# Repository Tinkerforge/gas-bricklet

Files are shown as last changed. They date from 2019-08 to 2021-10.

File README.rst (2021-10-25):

Gas Bricklet
============

**The development of this Bricklet was stopped.**

This repository contains the firmware source code and the hardware design
files. The documentation generator configs can be found at
https://github.com/Tinkerforge/generators

Repository Content
------------------

software/:
 * examples/: Examples for all supported languages
 * build/: Makefile and compiled files
 * src/: Source code of firmware
 * generate_makefile: Shell script to generate Makefile from cmake script

hardware/:
 * Contains kicad project files and additionally schematics as pdf

datasheets/:
 * Contains datasheets for sensors and complex ICs that are used

Hardware
--------

The hardware is designed with the open source EDA Suite KiCad
(http://www.kicad.org). Before you are able to open the files,
you have to install the Tinkerforge kicad-libraries
(https://github.com/Tinkerforge/kicad-libraries). You can either clone
them directly in hardware/ or clone them in a separate folder and
symlink them into hardware/
(ln -s kicad_path/kicad-libraries project_path/hardware). After that you
can open the .pro file in hardware/ with kicad and from there view and
modify the schematics and the PCB layout.

Software
--------

If you want to do your own Brick/Bricklet firmware development we highly
recommend that you use our build environment setup script and read the
tutorial (https://www.tinkerforge.com/en/doc/Tutorials/Tutorial_Build_Environment/Tutorial.html).

To compile the C code we recommend you to install the newest GNU Arm Embedded
Toolchain (https://launchpad.net/gcc-arm-embedded/+download).
You also need to install bricklib2 (https://github.com/Tinkerforge/bricklib2).

You can either clone it directly in software/src/ or clone it in a
separate folder and symlink it into software/src/
(ln -s bricklib_path/bricklib2 project_path/software/src/). Finally make sure to
have CMake installed (http://www.cmake.org/cmake/resources/software.html).

After that you can generate a Makefile from the cmake script with the
generate_makefile shell script (in software/) and build the firmware
by invoking make in software/build/. The firmware (.zbin) can then be found
in software/build/ and uploaded with brickv (click button "Flashing"
on start screen).

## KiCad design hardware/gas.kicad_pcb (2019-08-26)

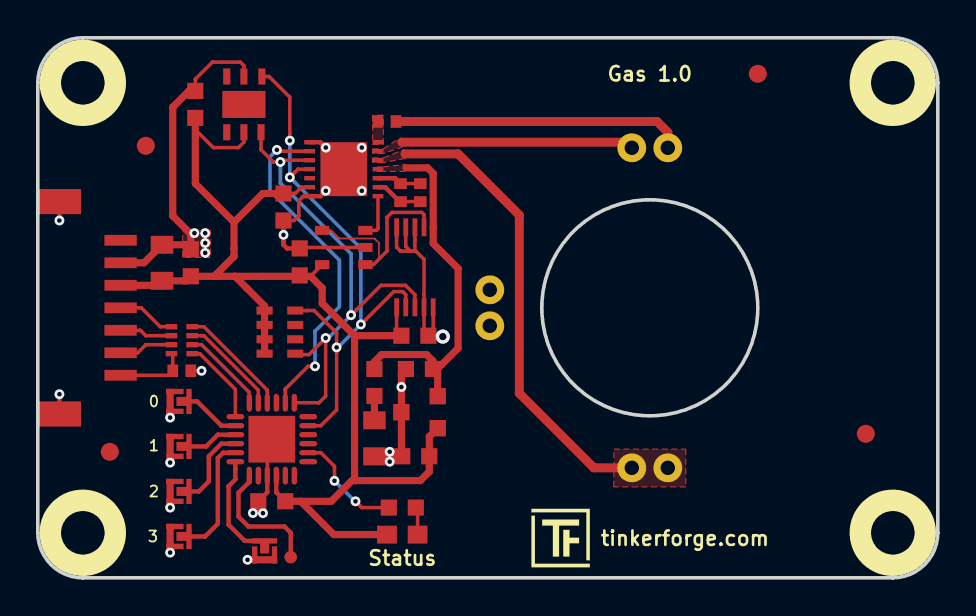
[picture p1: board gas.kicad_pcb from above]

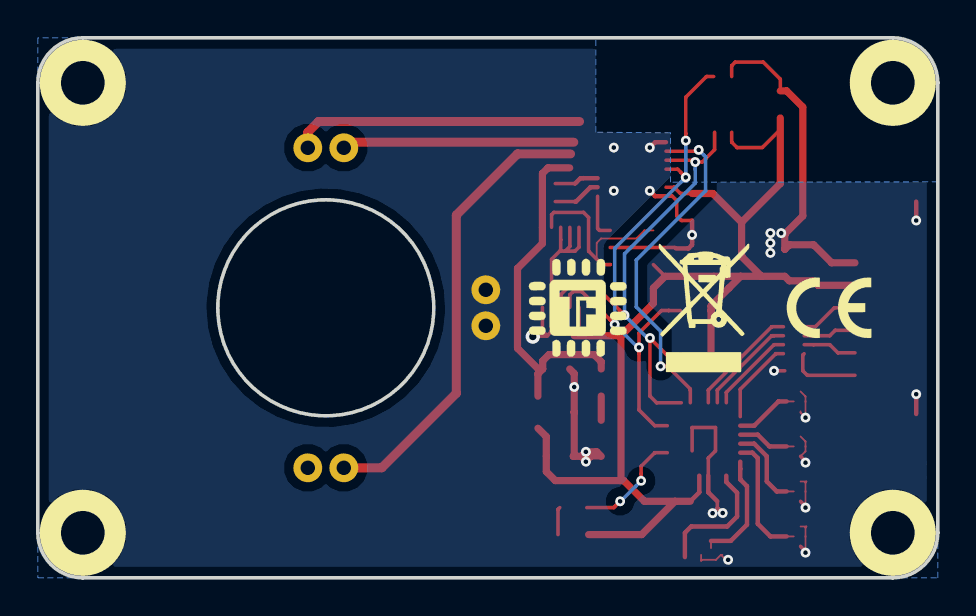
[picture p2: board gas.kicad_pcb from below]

Board: 2 copper layers, 50.0 x 30.0 mm, 43 parts (2 on the bottom side), 31 nets.

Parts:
C1: 220pF; C0402F
C2: 10uF; C0805
C3: 1uF; C0603F
C4, C5, C6, C7, C10, C11, C12: 100nF; C0603F
C8: 10uF TPSA106K010R0900; C0805P
C9: DNP; R0402F
D1: blue; D0603E
Fiducial_Mark: VAL**; Fiducial_Mark
Fiducial_Mark#2, Fiducial_Mark#3, Fiducial_Mark#4: VAL**; Fiducial_Mark
P1: CON-SENSOR2
P2: DEBUG; DEBUG_PAD
P3: BOOT; SolderJumper
P7: 0; SolderJumper
P8: 1; SolderJumper
P9: 2; SolderJumper
P10: 3; SolderJumper
R1, R2: 1k; R0603F
R3: 499k; R0402F
R4: 49,9; R0402F
RP1: 82; 4X0402
RP2: 10k; 0603X4
U1: XMC1300; QFN24-4x4mm-0.5mm
U2, U3, U4, U5: DRILL; DRILL_NP
U6: HDC1080; DFN6-30x30_humidity
U7: ISL60002; SOT23-3
U8: LMP91000; WSON-14-LMP91000
U9: MCP6041; SOT23-5
U10: MCP3423; MSOP10-0.5
U11: spec-sensor
VAL: WEEE_7mm
VAL#2: CE_5mm

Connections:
Enable: U1.20, U8.2
GND: C1.2, C2.1, C3.1, C4.2, C5.2, C6.2, C7.2, C8.2, C10.2, C11.2, C12.2, P1.2, P1.EP, P3.1, P7.1, P8.1, P9.1, P10.1, U1.9, U1.EXP, U6.2, U7.3, U8.1, U8.7, U8.15, U9.2, U10.3, U10.4, U10.5, U10.9, U10.10, U11.2, U11.3
unnamed: C1.1, P1.7, RP1.4
unnamed: C6.1, R2.2, U7.2, U8.11, U10.1
unnamed: C8.1, R2.1
unnamed: C9.1, R3.1, U8.10
unnamed: C9.2, R3.2, U8.9
unnamed: D1.2, R1.2
unnamed: P1.4, RP1.1
unnamed: P1.5, RP1.2
unnamed: P1.6, RP1.3
unnamed: P2.1, U1.7
unnamed: P3.2, U1.6
unnamed: R1.1, U1.14
unnamed: R4.1, U11.5
unnamed: R4.2, U8.14
unnamed: U8.8, U9.3
unnamed: U9.1, U9.4, U10.2
unnamed: U8.12, U11.1, U11.6
unnamed: U8.13, U11.4
S-CLK: RP1.7, U1.23
S-CS: RP1.8, U1.22
S-MISO: RP1.5, U1.1
S-MOSI: RP1.6, U1.24
SCL0: RP2.5, U1.19, U6.6, U8.3, U10.8
SDA0: RP2.8, U1.17, U6.1, U8.4, U10.7
SolderJumper0: P7.2, U1.2
SolderJumper1: P8.2, U1.3
SolderJumper2: P9.2, U1.4
SolderJumper3: P10.2, U1.5
VCC: C2.2, C3.2, C4.1, C5.1, C7.1, C10.1, C11.1, C12.1, D1.1, P1.3, RP2.1, RP2.2, RP2.3, RP2.4, U1.10, U6.5, U7.1, U8.6, U9.5, U10.6

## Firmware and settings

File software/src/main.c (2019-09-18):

/* gas-bricklet
 * Copyright (C) 2019 Olaf Lüke <olaf@tinkerforge.com>
 *
 * main.c: Initialization for Gas Bricklet
 *
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
 * You should have received a copy of the GNU Lesser General Public
 * License along with this library; if not, write to the
 * Free Software Foundation, Inc., 59 Temple Place - Suite 330,
 * Boston, MA 02111-1307, USA.
 */

#include <stdio.h>
#include <stdbool.h>

#include "configs/config.h"

#include "bricklib2/bootloader/bootloader.h"
#include "bricklib2/hal/system_timer/system_timer.h"
#include "bricklib2/logging/logging.h"
#include "communication.h"
#include "gas.h"

int main(void) {
	logging_init();
	logd("Start Gas Bricklet\n\r");

	communication_init();
	gas_init();

	while(true) {
		bootloader_tick();
		communication_tick();
		gas_tick();
	}
}

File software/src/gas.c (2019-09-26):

/* gas-bricklet
 * Copyright (C) 2019 Olaf Lüke <olaf@tinkerforge.com>
 *
 * gas.c: Driver for general Gas type and Concentration detection
 *
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
 * You should have received a copy of the GNU Lesser General Public
 * License along with this library; if not, write to the
 * Free Software Foundation, Inc., 59 Temple Place - Suite 330,
 * Boston, MA 02111-1307, USA.
 */

#include "gas.h"

#include "configs/config_gas.h"
#include "configs/config_lmp91000.h"
#include "configs/config_mcp3423.h"
#include "configs/config_hdc1080.h"

#include "bricklib2/hal/system_timer/system_timer.h"
#include "bricklib2/logging/logging.h"
#include "bricklib2/os/coop_task.h"

#include "communication.h"

#include "lmp91000.h"
#include "hdc1080.h"
#include "mcp3423.h"

#define GAS_CALIBRATION_PAGE           1
#define GAS_CALIBRATION_MAGIC_POS      0
#define GAS_CALIBRATION_DATA_POS       1 // 1 to 14
#define GAS_CALIBRATION_CHECKSUM_POS   15
#define GAS_CALIBRATION_MAGIC          0x12345678

#define GAS_TIME_BETWEEN_INIT_AND_TICK 300 // in ms

#define GAS_ADC_18BIT_MAX              262143
#define GAS_TEMPERATURE_THRESHOLD_ZERO 25.0
#define GAS_TEMPERATURE_THRESHOLD_SPAN 25.0

const uint32_t gas_tiagain_to_rgain[8] = {
	499000, 2735, 3476, 6903, 13618, 32706, 96737, 205713
};

// {Zero Low, Zero High, Span Low, Span High}
const double gas_sensor_compensation[][4] = {
	{0.0,   2.375, 0.6, 0.4}, // CO
	{1.7,  22.5,   1.2, 0.0}, // EtOH
	{0.0,   0.0,   0.3, 0.0}, // H2S
	{0.0,  15.0,   1.2, 0.5}, // SO2
	{0.0, - 1.6,   0.0, 0.4}, // NO2
	{0.0,   0.0,   0.0, 0.5}, // O3
	{0.0,   0.0,   0.0, 0.0}, // IAQ
	{0.0,   0.0,   0.0, 0.0}, // RESP
	{0.0,   0.0,   0.0, 0.0}, // O3/NO
};


CoopTask gas_task;
Gas gas;

uint32_t gas_task_read_register(const uint8_t address, const I2C_FIFO_REG_TYPE reg, const uint32_t length, uint8_t *data) {
	while(gas.i2c_mutex) {
		coop_task_yield();
	}

	gas.i2c_mutex = true;
	gas.i2c_fifo.address = address;

	uint32_t ret = i2c_fifo_coop_read_register(&gas.i2c_fifo, reg, length, data);

	gas.i2c_mutex = false;

	return ret;
}

uint32_t gas_task_write_register(const uint8_t address, const I2C_FIFO_REG_TYPE reg, const uint32_t length, const uint8_t *data, const bool send_stop) {
	while(gas.i2c_mutex) {
		coop_task_yield();
	}

	gas.i2c_mutex = true;
	gas.i2c_fifo.address = address;

	uint32_t ret = i2c_fifo_coop_write_register(&gas.i2c_fifo, reg, length, data, send_stop);

	gas.i2c_mutex = false;

	return ret;
}

uint32_t gas_task_read_direct(const uint8_t address, const uint32_t length, uint8_t *data, const bool restart) {
	while(gas.i2c_mutex) {
		coop_task_yield();
	}

	gas.i2c_mutex = true;
	gas.i2c_fifo.address = address;

	uint32_t ret = i2c_fifo_coop_read_direct(&gas.i2c_fifo, length, data, restart);

	gas.i2c_mutex = false;

	return ret;
}

uint32_t gas_task_write_direct(const uint8_t address, const uint32_t length, const uint8_t *data, const bool send_stop) {
	while(gas.i2c_mutex) {
		coop_task_yield();
	}

	gas.i2c_mutex = true;
	gas.i2c_fifo.address = address;

	uint32_t ret = i2c_fifo_coop_write_direct(&gas.i2c_fifo, length, data, send_stop);

	gas.i2c_mutex = false;

	return ret;
}

void gas_calibration_read(void) {
	uint32_t page[EEPROM_PAGE_SIZE/sizeof(uint32_t)];

	bootloader_read_eeprom_page(GAS_CALIBRATION_PAGE, page);
	uint32_t checksum = 0;
	for(uint8_t i = 0; i < GAS_CALIBRATION_CHECKSUM_POS; i++) {
		checksum = checksum ^ page[i];
	}

	if(page[GAS_CALIBRATION_MAGIC_POS] != GAS_CALIBRATION_MAGIC) {
		logd("Calibration Read: Wrong magic %x != %x\n\r", page[GAS_CALIBRATION_MAGIC_POS], GAS_CALIBRATION_MAGIC);
		return;
	}

	if(page[GAS_CALIBRATION_CHECKSUM_POS] != checksum) {
		logd("Calibration Read: Wrong checksum %x != %x\n\r", page[GAS_CALIBRATION_CHECKSUM_POS], checksum);
		return;
	}

	gas.calibration_adc_count_zero         = page[GAS_CALIBRATION_DATA_POS +  0];
	gas.calibration_temperature_zero       = page[GAS_CALIBRATION_DATA_POS +  1];
	gas.calibration_humidity_zero          = page[GAS_CALIBRATION_DATA_POS +  2];
	gas.calibration_compensation_zero_low  = page[GAS_CALIBRATION_DATA_POS +  3];
	gas.calibration_compensation_zero_high = page[GAS_CALIBRATION_DATA_POS +  4];
	gas.calibration_ppm_span               = page[GAS_CALIBRATION_DATA_POS +  5];
	gas.calibration_adc_count_span         = page[GAS_CALIBRATION_DATA_POS +  6];
	gas.calibration_temperature_span       = page[GAS_CALIBRATION_DATA_POS +  7];
	gas.calibration_humidity_span          = page[GAS_CALIBRATION_DATA_POS +  8];
	gas.calibration_compensation_span_low  = page[GAS_CALIBRATION_DATA_POS +  9];
	gas.calibration_compensation_span_high = page[GAS_CALIBRATION_DATA_POS + 10];
	gas.calibration_temperature_offset     = page[GAS_CALIBRATION_DATA_POS + 11];
	gas.calibration_humidity_offset        = page[GAS_CALIBRATION_DATA_POS + 12];
	gas.calibration_sensitivity            = page[GAS_CALIBRATION_DATA_POS + 13]; 


	// Use GAS_CALIBRATION_MAGIC here to differentiate between new
	// versions of calibration. Currently we only use three values here.
	gas.adc_count_zero     = gas.calibration_adc_count_zero;
	gas.na_per_ppm         = gas.calibration_sensitivity;
	gas.temperature_offset = gas.calibration_temperature_offset;
	gas.humidity_offset    = gas.calibration_temperature_offset;
}

void gas_calibration_write(void) {
	uint32_t page[EEPROM_PAGE_SIZE/sizeof(uint32_t)];

	page[GAS_CALIBRATION_MAGIC_POS    ] = GAS_CALIBRATION_MAGIC;

	page[GAS_CALIBRATION_DATA_POS +  0] = gas.calibration_adc_count_zero;
	page[GAS_CALIBRATION_DATA_POS +  1] = gas.calibration_temperature_zero;
	page[GAS_CALIBRATION_DATA_POS +  2] = gas.calibration_humidity_zero;
	page[GAS_CALIBRATION_DATA_POS +  3] = gas.calibration_compensation_zero_low;
	page[GAS_CALIBRATION_DATA_POS +  4] = gas.calibration_compensation_zero_high;
	page[GAS_CALIBRATION_DATA_POS +  5] = gas.calibration_ppm_span;
	page[GAS_CALIBRATION_DATA_POS +  6] = gas.calibration_adc_count_span;
	page[GAS_CALIBRATION_DATA_POS +  7] = gas.calibration_temperature_span;
	page[GAS_CALIBRATION_DATA_POS +  8] = gas.calibration_humidity_span;
	page[GAS_CALIBRATION_DATA_POS +  9] = gas.calibration_compensation_span_low;
	page[GAS_CALIBRATION_DATA_POS + 10] = gas.calibration_compensation_span_high;
	page[GAS_CALIBRATION_DATA_POS + 11] = gas.calibration_temperature_offset;
	page[GAS_CALIBRATION_DATA_POS + 12] = gas.calibration_humidity_offset;
	page[GAS_CALIBRATION_DATA_POS + 13] = gas.calibration_sensitivity;

	uint32_t checksum = 0;
	for(uint8_t i = 0; i < GAS_CALIBRATION_CHECKSUM_POS; i++) {
		checksum = checksum ^ page[i];
	}

	page[GAS_CALIBRATION_CHECKSUM_POS] = checksum;

	bootloader_write_eeprom_page(GAS_CALIBRATION_PAGE, page);
}
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

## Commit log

2019-02-06 added schematic
    [gas.sch]
2019-02-06 added pcb design
    [gas.kicad_pcb, gas.sch]
2019-02-07 pcb design
    [gas.kicad_pcb]
2019-02-07 final pcb design
    [gas.kicad_pcb]
2019-02-07 added fiducial marks
    [gas.kicad_pcb]
2019-03-20 changed mcu to xmc 1300, new pcb design,
    [gas.kicad_pcb, gas.sch]
2019-03-20 changed to xmc1300, new pcb design for part clearance, added smd M3 spacer
    [gas.kicad_pcb]
2019-03-21 updated M3 spacer footprint, drc check
    [gas.kicad_pcb]
2019-03-21 changed status led placement, plotted gerber files
    [gas.kicad_pcb]
2019-04-09 Fix USIC ch0/1 comment
    [gas.sch]
2019-04-09 changed debugpin
    [gas.kicad_pcb, gas.sch]
2019-05-03 new design
    [gas.sch]
2019-05-29 all new design
    [gas.kicad_pcb, gas.sch]
2019-05-29 changes in pcb design
    [gas.kicad_pcb, gas.sch]
2019-06-03 final prototype
    [gas.kicad_pcb]
2019-08-15 corrected wrong pinout of ISL60002 in schematic and pcb design
    [gas.kicad_pcb, gas.sch]
2019-08-15 drc check
    [gas.kicad_pcb]
2019-08-26 add fiducials
    [gas.kicad_pcb]
2019-09-18 Add firmware
    [cmake_config_custom.txt]
2019-09-18 Add missing line breaks in logging
    [gas.c]
2019-09-18 Add temperature and humidity offset to calibration
2019-09-18 Remove gas type from calibration (set pyhsically on the PCB)
2019-09-18 Add gas type detection support
    This is done through solder jumpers on the PCB.
2019-09-26 Use inverse ADC value.
    VOUT of LMP91000 is connected to "-" of MCP3423.
    Thus an increase of VOUT will result in a decreased ADC count.
2021-10-25 Update KiCad link
    https://www.kicad.org/blog/2021/10/Avoid-links-to-former-kicad-domain/

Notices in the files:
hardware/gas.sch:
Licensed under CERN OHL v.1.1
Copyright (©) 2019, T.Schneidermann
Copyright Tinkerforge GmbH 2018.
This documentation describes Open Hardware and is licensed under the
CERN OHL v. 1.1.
